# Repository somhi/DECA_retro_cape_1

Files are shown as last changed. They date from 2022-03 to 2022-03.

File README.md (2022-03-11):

# Arrow DECA Retro Cape 1 (4 layer - embedded SDRAM - Edge connector)

**STATUS (10/03/22):  prototype design work in progress**

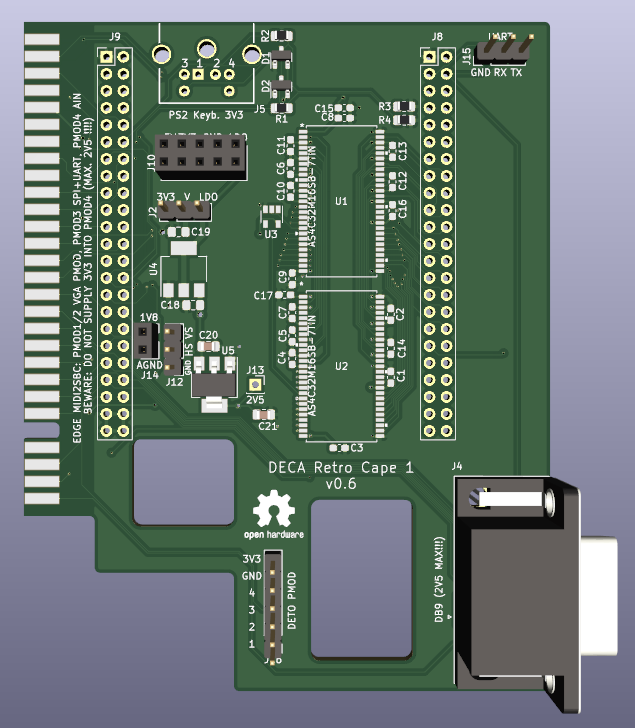
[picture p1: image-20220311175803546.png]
Project has been developed with KiCAD 6.0. 

All credits for SDRAM design goes to Tom Verbeure from whom I've taken his [original design  files](https://github.com/tomverbeure/arrow_deca_retro_cape) and adapted to my own design.

As I already developed an Edge to Pmod PCB, I'll be using here attached to the DECA cape. See details at https://github.com/somhi/MIDI_I2S_SBC_Pmod_Edge_Interface

### **Schematic**

 [arrow_deca_retro_cape.pdf](arrow_deca_retro_cape.pdf) 

### **Features**

* 

### 3D model

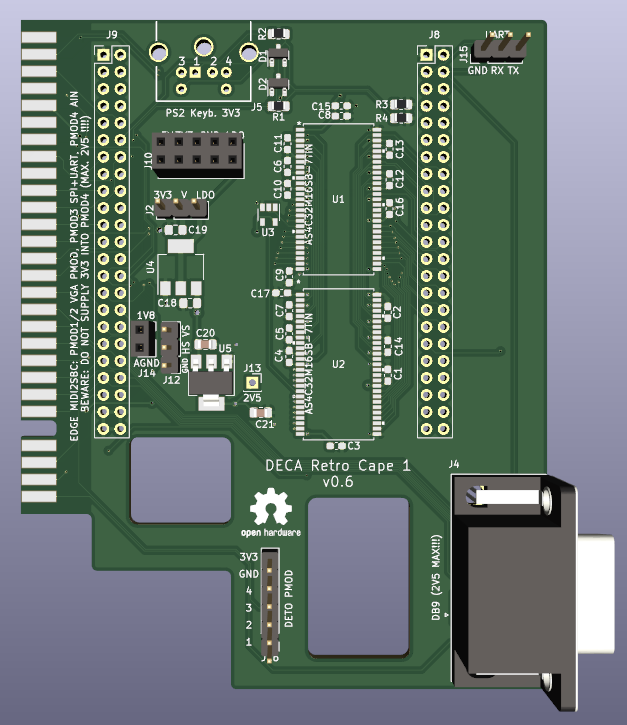
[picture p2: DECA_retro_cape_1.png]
DECA_retro_cape_1


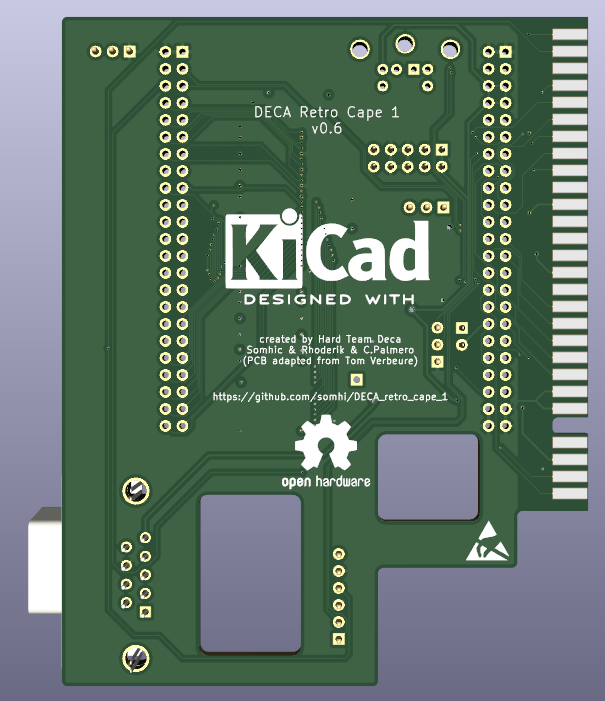
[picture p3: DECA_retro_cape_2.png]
DECA_retro_cape_2


### **Additional notes**

* 

### **Jumper Selection**

* 

### Changelog

v0.5  routed finalized

v0.6  embedded SDRAM version only. External Mister module removed in order to improve signal integrity.

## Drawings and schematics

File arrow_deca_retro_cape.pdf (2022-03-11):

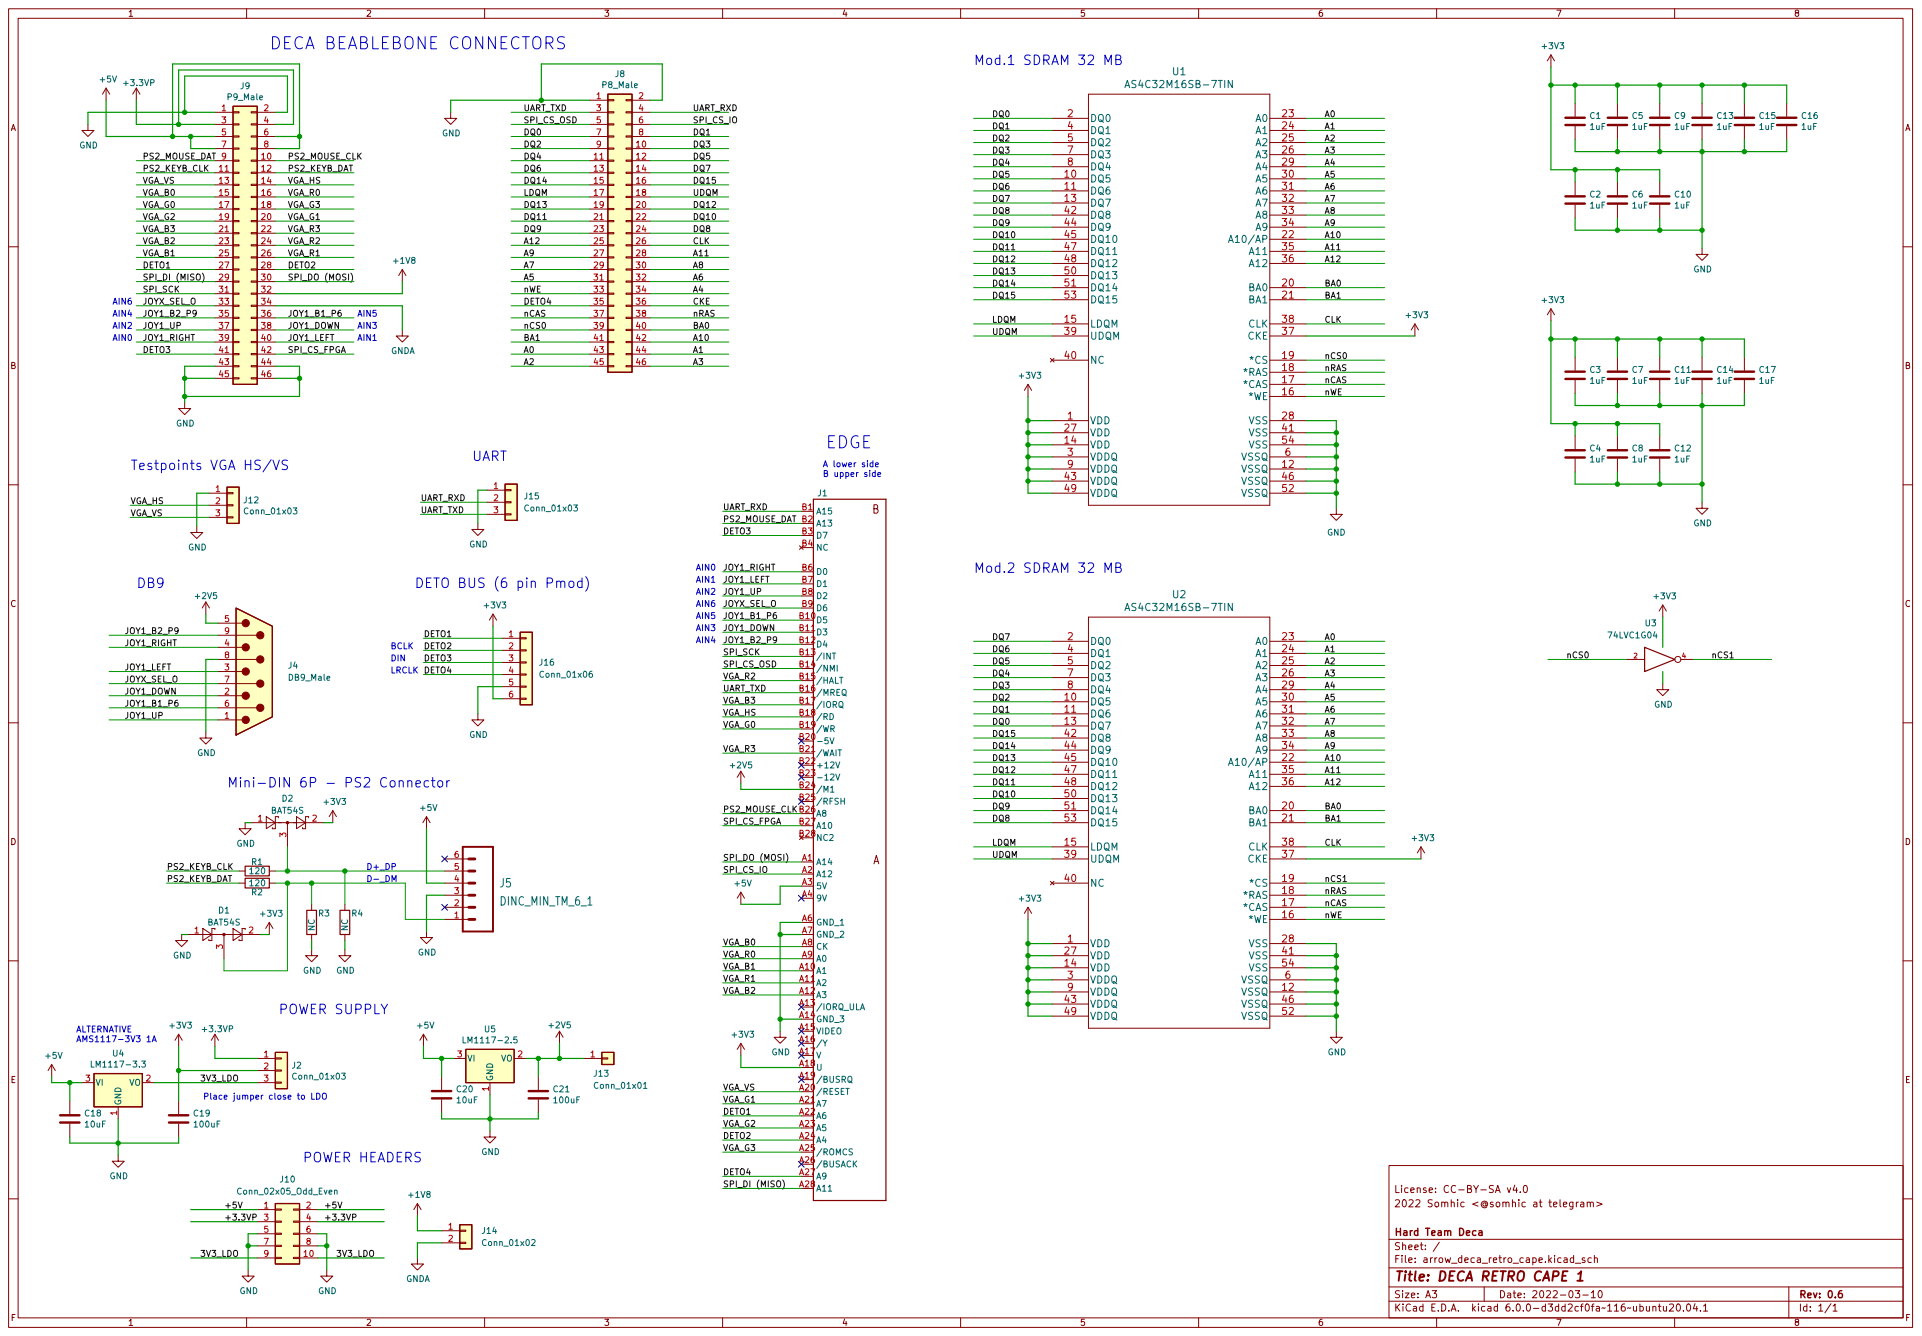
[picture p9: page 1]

2022 Somhic <@somhic at telegram>

File: arrow_deca_retro_cape.kicad_sch Sheet: / Hard Team Deca

Id: 1/1 Title: DECA RETRO CAPE 1

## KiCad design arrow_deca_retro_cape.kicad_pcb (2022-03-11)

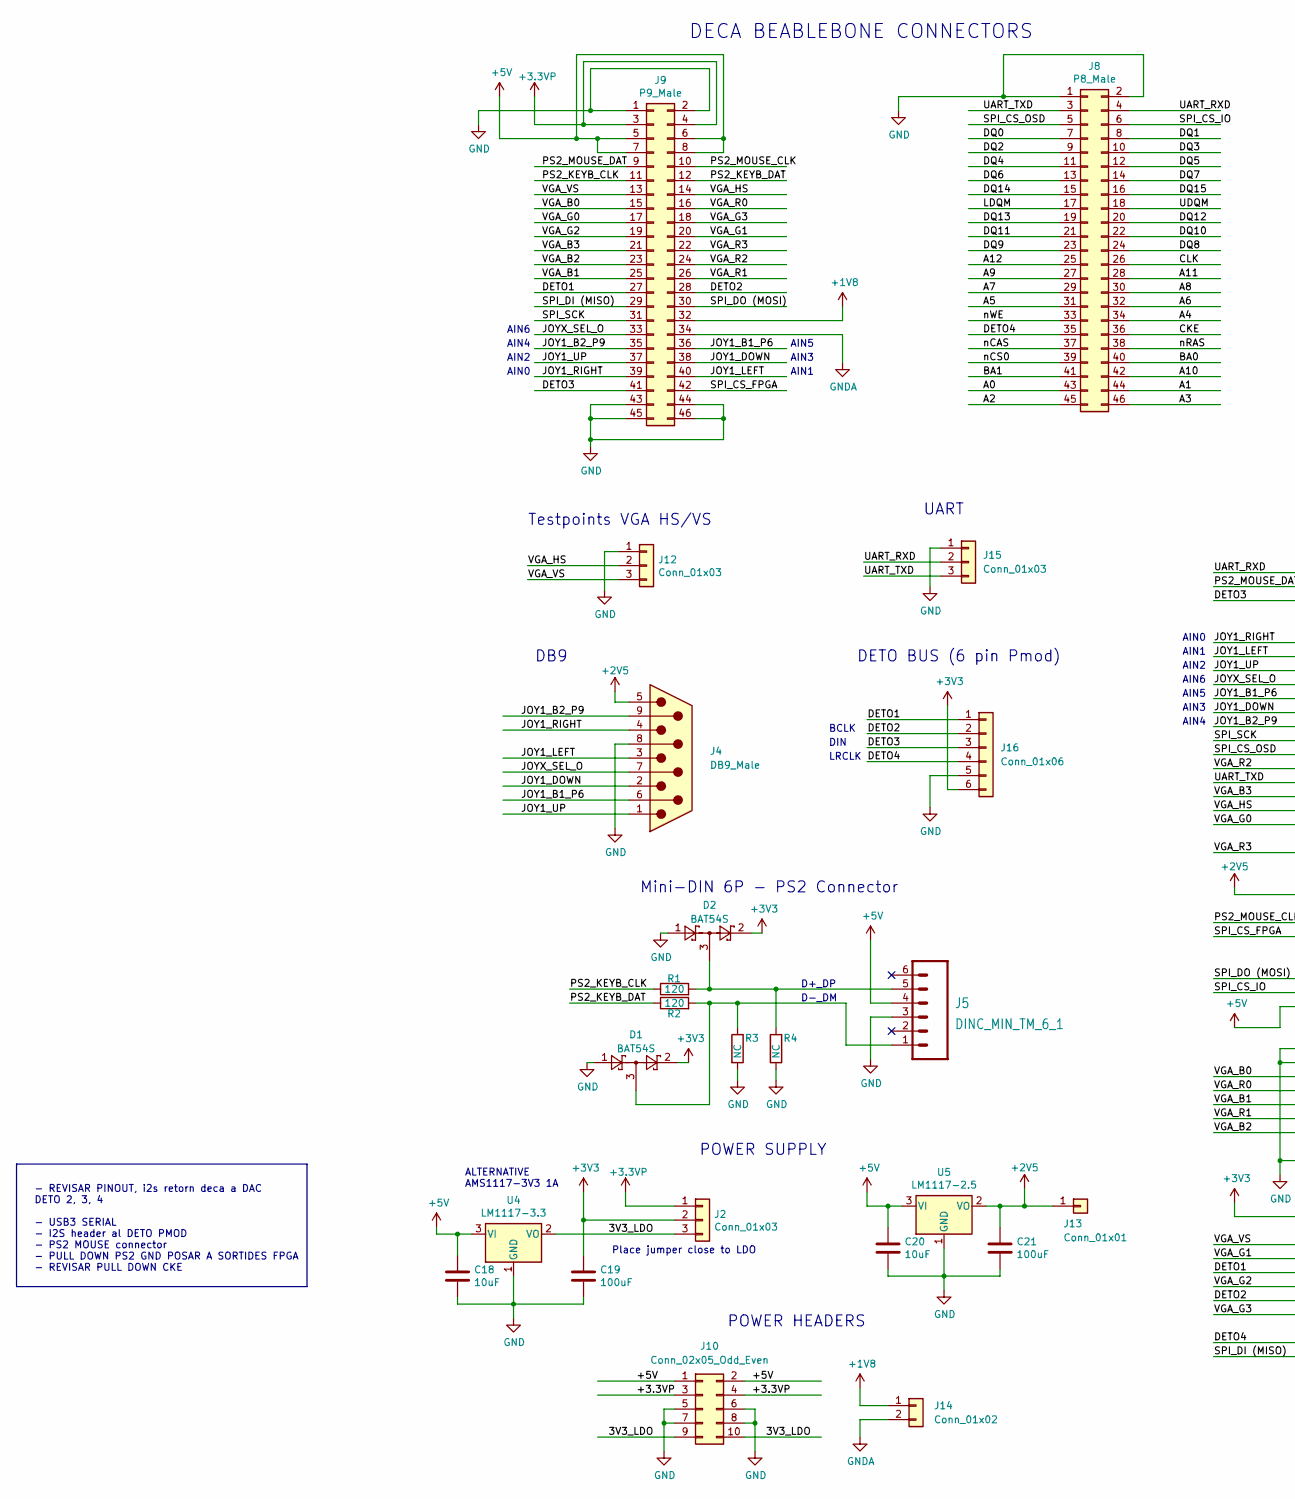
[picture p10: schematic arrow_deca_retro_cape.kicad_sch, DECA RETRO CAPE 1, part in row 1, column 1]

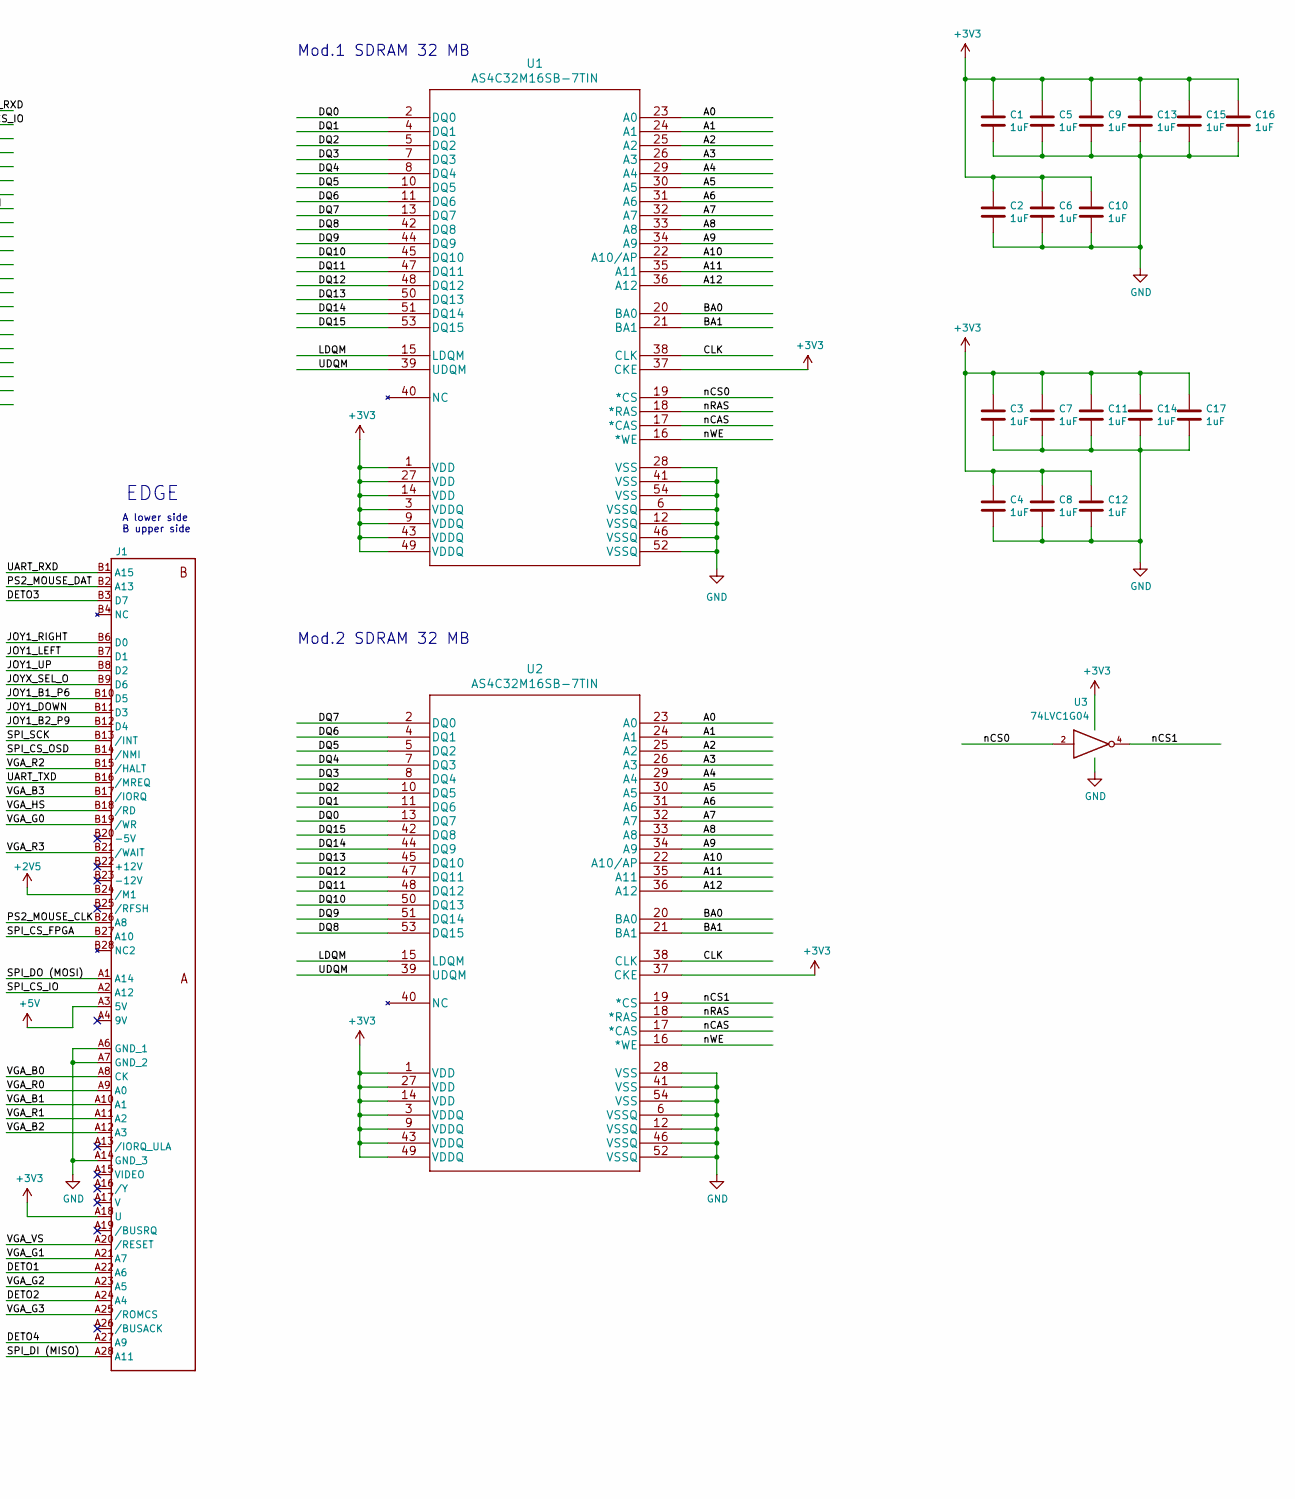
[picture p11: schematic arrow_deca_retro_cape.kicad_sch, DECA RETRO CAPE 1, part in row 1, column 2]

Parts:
C1, C2, C3, C4, C5, C6, C7, C8, C9, C10, C11, C12, C13, C14, C15, C16, C17: 1uF; C_0603_1608Metric_Pad1.05x0.95mm_HandSolder
C18: 10uF; C_0805_2012Metric_Pad1.15x1.40mm_HandSolder
C19: 100uF; C_0805_2012Metric_Pad1.15x1.40mm_HandSolder
C20: 10uF; C_0805_2012Metric_Pad1.18x1.45mm_HandSolder
C21: 100uF; C_0805_2012Metric_Pad1.18x1.45mm_HandSolder
D1, D2: BAT54S; SOT-23
J1: ZXSP_ED2X28_SPE_SOL_EDGE; 2X28_SPE2
J2, J12, J15: Conn_01x03; PinHeader_1x03_P2.54mm_Vertical
J4: DB9_Male; DSUB-9_Male_Horizontal_P2.77x2.84mm_EdgePinOffset9.90mm_Hou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
J5: DINC_MIN_TM_6_1; DINC_MIN_TM_6_1PRIMARY
J8: P8_Male; PinHeader_2x23_P2.54mm_Vertical
J9: P9_Male; PinHeader_2x23_P2.54mm_Vertical
J10: Conn_02x05_Odd_Even; PinSocket_2x05_P2.54mm_Vertical
J13: Conn_01x01; PinSocket_1x01_P2.54mm_Vertical
J14: Conn_01x02; PinSocket_1x02_P2.54mm_Vertical
J16: Conn_01x06; PinHeader_1x06_P2.54mm_Vertical
R1, R2: 120; R_0805_2012Metric_Pad1.20x1.40mm_HandSolder
R3, R4: NC; R_0805_2012Metric_Pad1.20x1.40mm_HandSolder
U1, U2: AS4C32M16SB-7TIN
U3: 74LVC1G04; SOT-23-5
U4: LM1117-3.3; SOT-223-3_TabPin2
U5: LM1117-2.5; SOT-223-3_TabPin2

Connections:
+1V8: J9.32, J14.1
+2V5: C21.1, J1.B24 (/M1), J4.5, J13.1, U5.2 (VO)
+3.3VP: J2.1, J9.3, J9.4, J10.3, J10.4
+3V3: C1.1, C2.1, C3.1, C4.1, C5.1, C6.1, C7.1, C8.1, C9.1, C10.1, C11.1, C12.1, C13.1, C14.1, C15.1, C16.1, C17.1, C19.1, D1.2, D2.2, J1.A18 (U), J2.2, J16.6, U1.1 (VDD), U1.3 (VDDQ), U1.9 (VDDQ), U1.14 (VDD), U1.27 (VDD), U1.37 (CKE), U1.43 (VDDQ), U1.49 (VDDQ), U2.1 (VDD), U2.3 (VDDQ), U2.9 (VDDQ), U2.14 (VDD), U2.27 (VDD), U2.37 (CKE), U2.43 (VDDQ), U2.49 (VDDQ), U3.5 (VCC)
+5V: C18.1, C20.1, J1.A3 (5V), J5.4, J9.5, J9.6, J9.7, J9.8, J10.1, J10.2, U4.3 (VI), U5.3 (VI)
/3V3_LDO: J2.3, J10.9, J10.10, U4.2 (VO)
/A0: J8.43, U1.23 (A0), U2.23 (A0)
/A1: J8.44, U1.24 (A1), U2.24 (A1)
/A2: J8.45, U1.25 (A2), U2.25 (A2)
/A3: J8.46, U1.26 (A3), U2.26 (A3)
/A4: J8.34, U1.29 (A4), U2.29 (A4)
/A5: J8.31, U1.30 (A5), U2.30 (A5)
/A6: J8.32, U1.31 (A6), U2.31 (A6)
/A7: J8.29, U1.32 (A7), U2.32 (A7)
/A8: J8.30, U1.33 (A8), U2.33 (A8)
/A9: J8.27, U1.34 (A9), U2.34 (A9)
/A10: J8.42, U1.22 (A10/AP), U2.22 (A10/AP)
/A11: J8.28, U1.35 (A11), U2.35 (A11)
/A12: J8.25, U1.36 (A12), U2.36 (A12)
/BA0: J8.40, U1.20 (BA0), U2.20 (BA0)
/BA1: J8.41, U1.21 (BA1), U2.21 (BA1)
/CKE: J8.36
/CLK: J8.26, U1.38 (CLK), U2.38 (CLK)
/DETO1: J1.A22 (A6), J9.27, J16.1
/DETO2: J1.A24 (A4), J9.28, J16.2
/DETO3: J1.B3 (D7), J9.41, J16.3
/DETO4: J1.A27 (A9), J8.35, J16.4
/DQ0: J8.7, U1.2 (DQ0), U2.13 (DQ7)
/DQ1: J8.8, U1.4 (DQ1), U2.11 (DQ6)
/DQ2: J8.9, U1.5 (DQ2), U2.10 (DQ5)
/DQ3: J8.10, U1.7 (DQ3), U2.8 (DQ4)
/DQ4: J8.11, U1.8 (DQ4), U2.7 (DQ3)
/DQ5: J8.12, U1.10 (DQ5), U2.5 (DQ2)
/DQ6: J8.13, U1.11 (DQ6), U2.4 (DQ1)
/DQ7: J8.14, U1.13 (DQ7), U2.2 (DQ0)
/DQ8: J8.24, U1.42 (DQ8), U2.53 (DQ15)
/DQ9: J8.23, U1.44 (DQ9), U2.51 (DQ14)
/DQ10: J8.22, U1.45 (DQ10), U2.50 (DQ13)
/DQ11: J8.21, U1.47 (DQ11), U2.48 (DQ12)
/DQ12: J8.20, U1.48 (DQ12), U2.47 (DQ11)
/DQ13: J8.19, U1.50 (DQ13), U2.45 (DQ10)
/DQ14: J8.15, U1.51 (DQ14), U2.44 (DQ9)
/DQ15: J8.16, U1.53 (DQ15), U2.42 (DQ8)
/JOY1_B1_P6: J1.B10 (D5), J4.6, J9.36
/JOY1_B2_P9: J1.B12 (D4), J4.9, J9.35
/JOY1_DOWN: J1.B11 (D3), J4.2, J9.38
/JOY1_LEFT: J1.B7 (D1), J4.3, J9.40
/JOY1_RIGHT: J1.B6 (D0), J4.4, J9.39
/JOY1_UP: J1.B8 (D2), J4.1, J9.37
/JOYX_SEL_O: J1.B9 (D6), J4.7, J9.33
/LDQM: J8.17, U1.15 (LDQM), U2.15 (LDQM)
/PS2_KEYB_CLK: J9.11, R1.1
/PS2_KEYB_DAT: J9.12, R2.1
/PS2_MOUSE_CLK: J1.B26 (A8), J9.10
/PS2_MOUSE_DAT: J1.B2 (A13), J9.9
/SPI_CS_FPGA: J1.B27 (A10), J9.42
/SPI_CS_IO: J1.A2 (A12), J8.6
/SPI_CS_OSD: J1.B14 (/NMI), J8.5
/SPI_DI (MISO): J1.A28 (A11), J9.29
/SPI_DO (MOSI): J1.A1 (A14), J9.30
/SPI_SCK: J1.B13 (/INT), J9.31
/UART_RXD: J1.B1 (A15), J8.4, J15.2
/UART_TXD: J1.B16 (/MREQ), J8.3, J15.3
/UDQM: J8.18, U1.39 (UDQM), U2.39 (UDQM)
/VGA_B0: J1.A8 (CK), J9.15
/VGA_B1: J1.A10 (A1), J9.25
/VGA_B2: J1.A12 (A3), J9.23
/VGA_B3: J1.B17 (/IORQ), J9.21
/VGA_G0: J1.B19 (/WR), J9.17
/VGA_G1: J1.A21 (A7), J9.20
/VGA_G2: J1.A23 (A5), J9.19
/VGA_G3: J1.A25 (/ROMCS), J9.18
/VGA_HS: J1.B18 (/RD), J9.14, J12.2
/VGA_R0: J1.A9 (A0), J9.16
/VGA_R1: J1.A11 (A2), J9.26
/VGA_R2: J1.B15 (/HALT), J9.24
/VGA_R3: J1.B21 (/WAIT), J9.22
/VGA_VS: J1.A20 (/RESET), J9.13, J12.3
/nCAS: J8.37, U1.17 (*CAS), U2.17 (*CAS)
/nCS0: J8.39, U1.19 (*CS), U3.2
/nCS1: U2.19 (*CS), U3.4
/nRAS: J8.38, U1.18 (*RAS), U2.18 (*RAS)
/nWE: J8.33, U1.16 (*WE), U2.16 (*WE)
GND: C1.2, C2.2, C3.2, C4.2, C5.2, C6.2, C7.2, C8.2, C9.2, C10.2, C11.2, C12.2, C13.2, C14.2, C15.2, C16.2, C17.2, C18.2, C19.2, C20.2, C21.2, D1.1, D2.1, J1.A6 (GND_1), J1.A7 (GND_2), J1.A14 (GND_3), J4.8, J5.3, J8.1, J8.2, J9.1, J9.2, J9.43, J9.44, J9.45, J9.46, J10.5, J10.6, J10.7, J10.8, J12.1, J15.1, J16.5, R3.2, R4.2, U1.6 (VSSQ), U1.12 (VSSQ), U1.28 (VSS), U1.41 (VSS), U1.46 (VSSQ), U1.52 (VSSQ), U1.54 (VSS), U2.6 (VSSQ), U2.12 (VSSQ), U2.28 (VSS), U2.41 (VSS), U2.46 (VSSQ), U2.52 (VSSQ), U2.54 (VSS), U3.3 (GND), U4.1 (GND), U5.1 (GND)
GNDA: J9.34, J14.2
unnamed: D1.3, J5.1, R2.2, R3.1
unnamed: D2.3, J5.5, R1.2, R4.1

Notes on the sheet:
D-_DM
Mod.1 SDRAM 32 MB
POWER HEADERS
ALTERNATIVE AMS1117-3V3 1A
Testpoints VGA HS/VS
AIN2
BCLK
AIN6
DB9
DIN
AIN3
POWER SUPPLY
AIN1
Mod.2 SDRAM 32 MB
LRCLK
AIN5
DECA BEABLEBONE CONNECTORS
AIN0
AIN4
Place jumper close to LDO
A lower side B upper side
UART
D+_DP
Mini-DIN 6P - PS2 Connector
- REVISAR PINOUT, i2s retorn deca a DAC DETO 2, 3, 4 - USB3 SERIAL - I2S header al DETO PMOD - PS2 MOUSE connector - PULL DOWN PS2 GND POSAR A SORTIDES FPGA - REVISAR PULL DOWN CKE
DETO BUS (6 pin Pmod)
EDGE

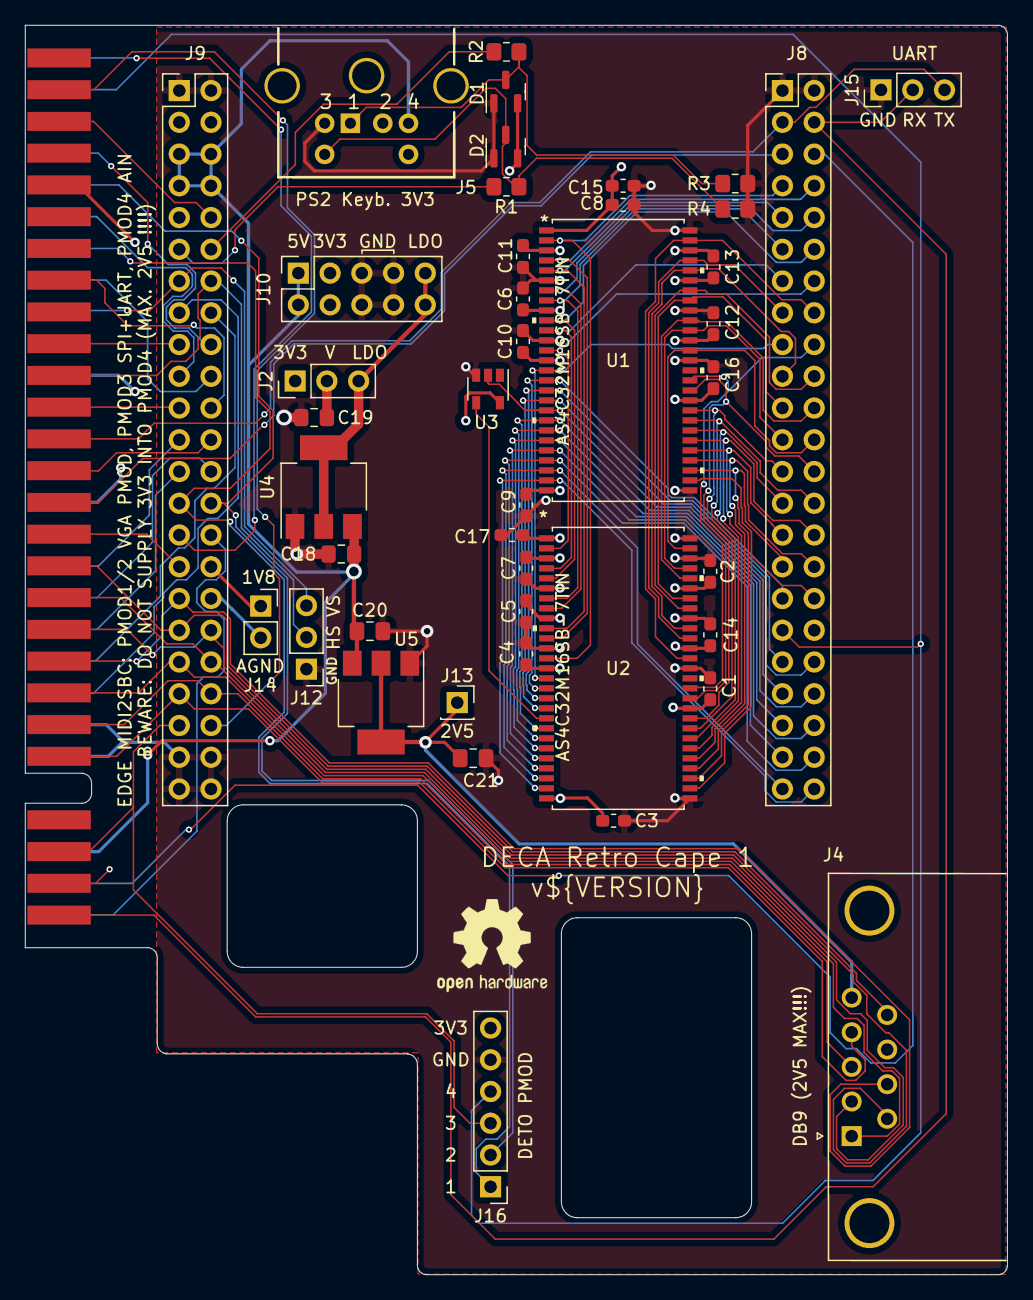
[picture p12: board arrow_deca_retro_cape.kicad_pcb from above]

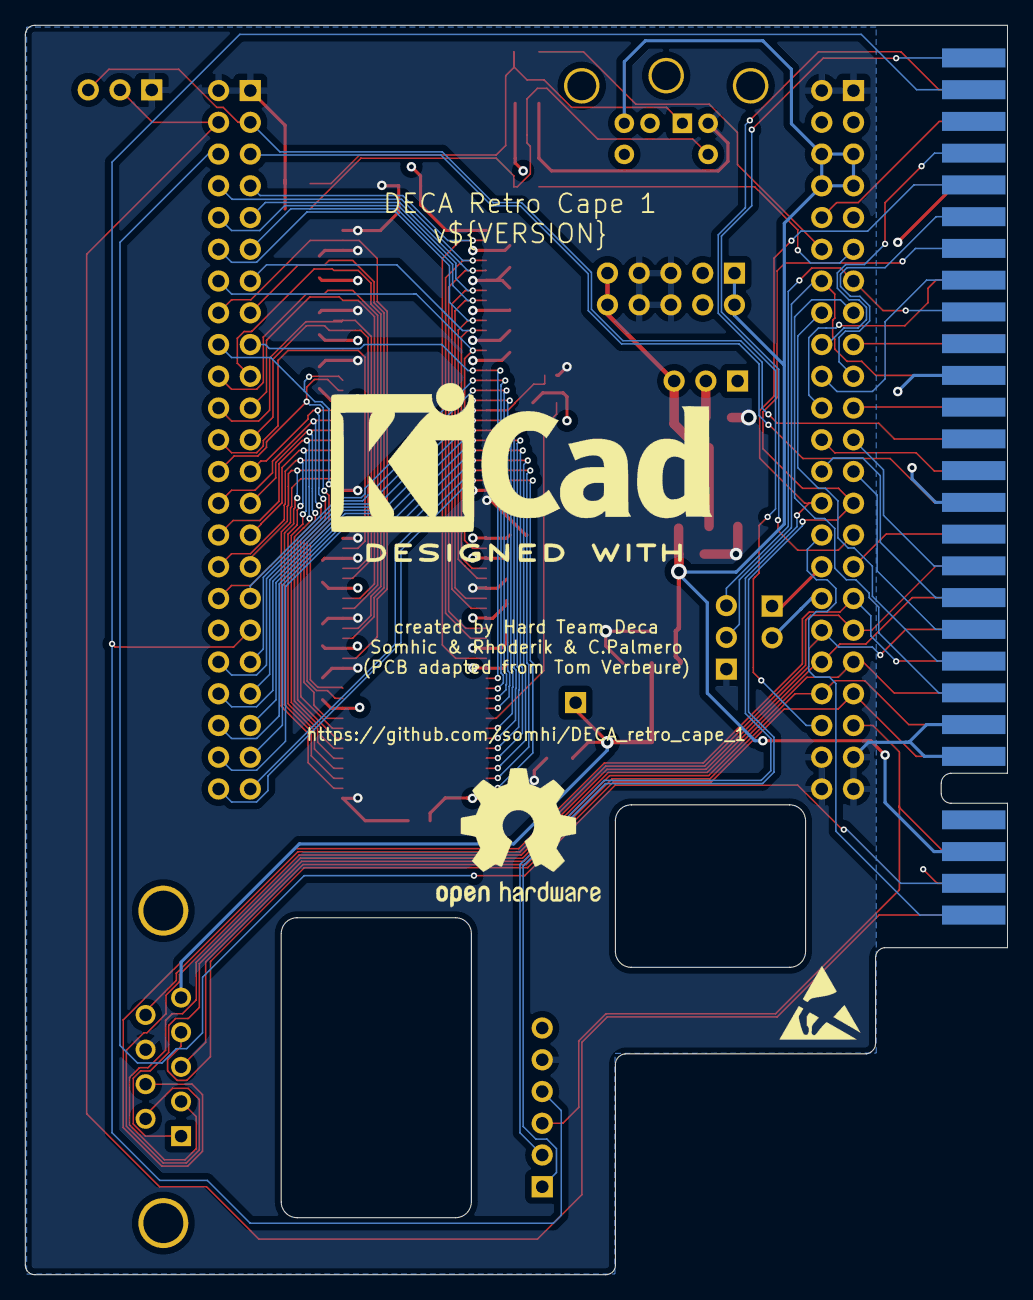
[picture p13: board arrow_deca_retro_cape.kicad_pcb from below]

Board: 4 copper layers, 78.6 x 100.0 mm, 48 parts (3 on the bottom side), 86 nets.

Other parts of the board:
LO1: KiCad-Logo2_12mm_SilkScreen
LO2: OSHW-Logo2_9.8x8mm_SilkScreen
LO3: OSHW-Logo2_14.6x12mm_SilkScreen
LO4: ESD-Logo_6.6x6mm_SilkScreen

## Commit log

2022-03-10 added Deto pmod
    [arrow_deca_retro_cape.kicad_pcb, arrow_deca_retro_cape.kicad_sch]
2022-03-10 v0.5 routing finalized
    [DECA_Cape1_multicomputer_v0.51_WIP.ods, arrow_deca_retro_cape.kicad_pcb, arrow_deca_retro_cape.kicad_sch]
2022-03-11 update before split
    [DECA_Cape1_multicomputer_v0.51_WIP.ods, arrow_deca_retro_cape.kicad_pcb, arrow_deca_retro_cape.kicad_sch]
2022-03-11 v0.6 embedded SDRAM only version
    [arrow_deca_retro_cape.kicad_pcb, arrow_deca_retro_cape.kicad_sch]

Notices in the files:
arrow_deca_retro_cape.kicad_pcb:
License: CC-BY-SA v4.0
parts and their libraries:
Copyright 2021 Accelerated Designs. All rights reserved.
